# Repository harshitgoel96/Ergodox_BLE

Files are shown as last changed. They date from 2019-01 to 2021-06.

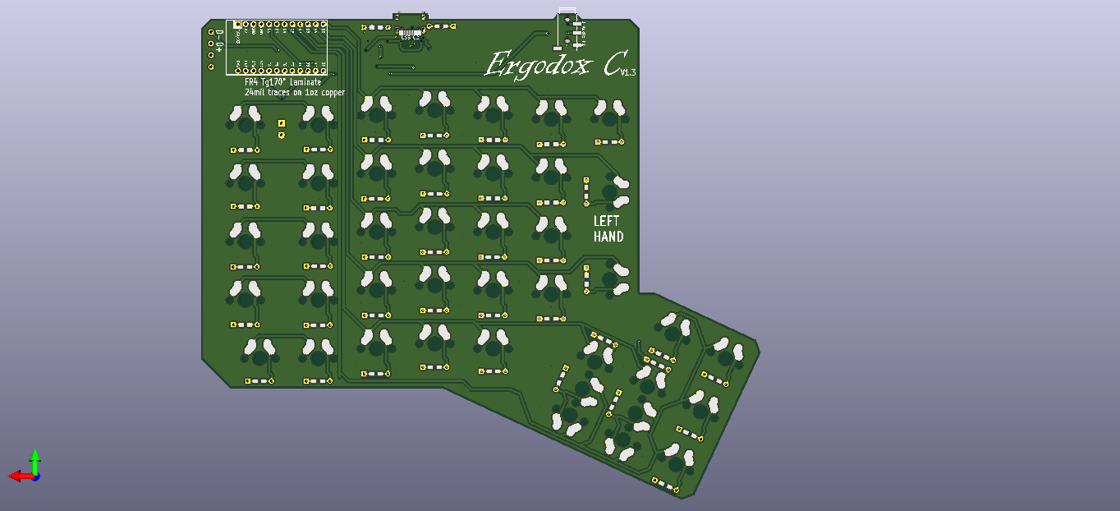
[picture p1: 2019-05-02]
ErgodoxBle/images/Left.png

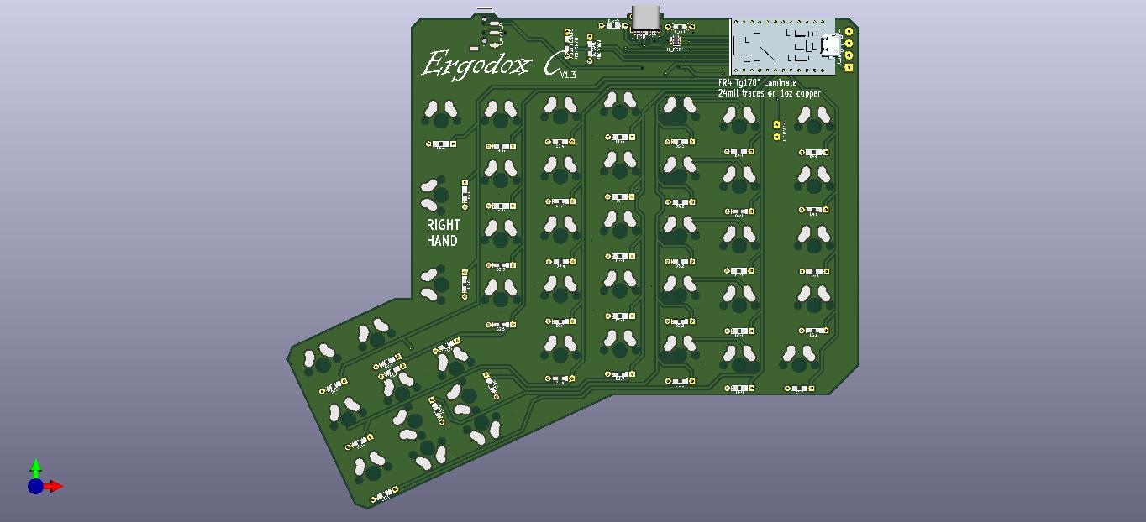
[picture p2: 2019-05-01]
ErgodoxBle/images/Right.jpg

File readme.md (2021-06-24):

# There is no active development on this keyboard. Feel free to do whatever you want. I have moved to Pteron36.
The PCB is in working statue, but no further support or development will be done on this project.
------------------------------------------------------------------------------------------------------------------------------------------
Ergodox BLE
===========

I love my [Ergodox](https://i.imgur.com/aIGm8G6h.jpg) , but it is not Bluetooth. I recently got to know about Bluemicro from u/jpconstantineau which is replacement for pro micro with BLE built in, and I also got to know about Proton C, which has USB C connector and is built for QMK. The original Ergodox uses Tinsy and Ergodone uses pro micro. Both the PCBs don't have support for either of the MCU directly and so I got to work and redid the PCB and I came up with this.

This is my first attempt at making a PCB and I need help from PCB hardware experts if everything is ok or do I need make some changes.

The Ergodox Keyboard was originally developed by “Dox” (Dominic Beauchamp). 

------------------------------------------------------------------------------------------------------------------------------------------
There has ben lot of progress, the complete timeline of the project is available in [Project update](./project_udpate.md) file

First prototype assembled   
Ergodox C

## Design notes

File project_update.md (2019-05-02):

## What has been happening in the project ?

* **8-Jan-2019**  
    Realised ergodox was the best keyboard I have. Need to make one more for home.  

* **9-Jan-2019**  
    Got to know about bluemicro, a ble capable for promicro. Decided that I will make the new ergodox bluetooth.  

* **10-Jan-2019**  
    After chatting with jpconstantineau, realise that existing ergodone or ergodox are not going to work with BlueMicro due to placement issues. Decided to mod only the ergodone case to fit bluemicro on one side.  

* **14-Jan 2019**  
    Further dicusions with jpconstantineau made me realised that i2c at the moment is not supported by bluemicro, and will take time. At the same time got to know about Proton-C. Decided to modify the existing Ergodox PCB.  

* **16-Jan-2019**  
    Modifing existing pcb was tough due to my limited knowledge about kicad.  

* **19-Jan 2019**  
    Role up the sleeve and decided to remake a new pcb.  

* **20-Jan-2019**  
    Added clearance for Proton-C, make sure the edge cuts are within existing Ergodone case.  

* **21-Jan-2019**  
    Realised it was simple enough to change the footprints on the schema and make it work with the kicad libs and footprints that I had.  

* **22-Jan-2019**  
    USB-C is the future, added it to the PCB. Always look to the future.  

* **23-Jan-2019**  
    Generate Gerbers, and schema pdf  to get feedback from a few of people.  

* **24-Jan-2019**  
    Feedback was positive. Gave order to JLCPCB. Fingers crossed.
    
* **30-Jan-2019**   
    Used lister's case to create acrylic case with clearance for USB-C and connection pads.
    
----------------------------------------------------------------------------------------------------------------------------------------

* **24-Mar-2019**
    I have been lazy updating the post, so here are all the updates
    * PCBs have been recieved, wiring looks ok, USB C pads are too small to handsolder, will have to replace it with something more easy to hand solder. ToDo.
    * Bluemicro has been assembled, easy to do if you can ready the marking on PCB and Component reels.
    * I have built the firmware for bluemicro, and did some test unassembeled. Bluetooth working as expected, no latency issues for me so far.
    * PCB has a few diodes in place, just to test things out before I solder in every thing.
    * Female headers are in place to support removal for MCU if and when required. Soldering diodes leg/wire on MCU itself is bit tricky. Trying to make it work at the moment.
* **25-Mar-2019**
    * Finally decided to hard solder the MCU. Firmware mostly works fine, need to flip the right hand mapping to make it work correctly
* **29-Mar-2019**
    * The develop branch of BlueMicro firmware is now being used. There is no connectivity or latency issue being observerd. Currently testing out the keyboard without any layers. This is to test out the hardware and firmware without have any complex code or marcro.
	
----------------------------------------------------------------------------------------------------------------------------------------

* **01-May-2019**
	ErgodoxC v1.3 released. This is most probably the last version of the PCB. Dual side USB C, USB ESD protection have been added. Case design updated for this pcb.
* **02-May-2019**
	Case files updated with plate for Alps Switches.

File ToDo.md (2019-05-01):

ToDo List
=========

This list is just for reference, there is no priority/ETA set for any of these fixes

* ~~USB C footprint used here is not good enough for hand solder, will need to replace with a more expensive one.~~ Decided to keep the smd one due to simpler wiring
* There is no way to access the ON/OFF or replace battery on the case. No idea how I can fix this. Also will need some pins to wire up some pins from bluemicro for easy flashing and support for on/off switch on both CR2032 and Li/Po version. Needs brainstorming.

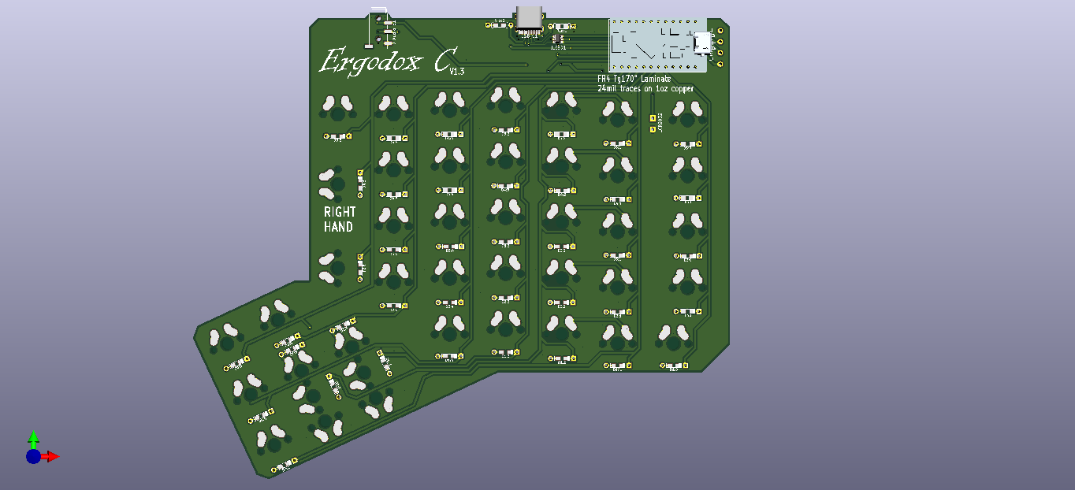
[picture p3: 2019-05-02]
ErgodoxBle/images/Right.png

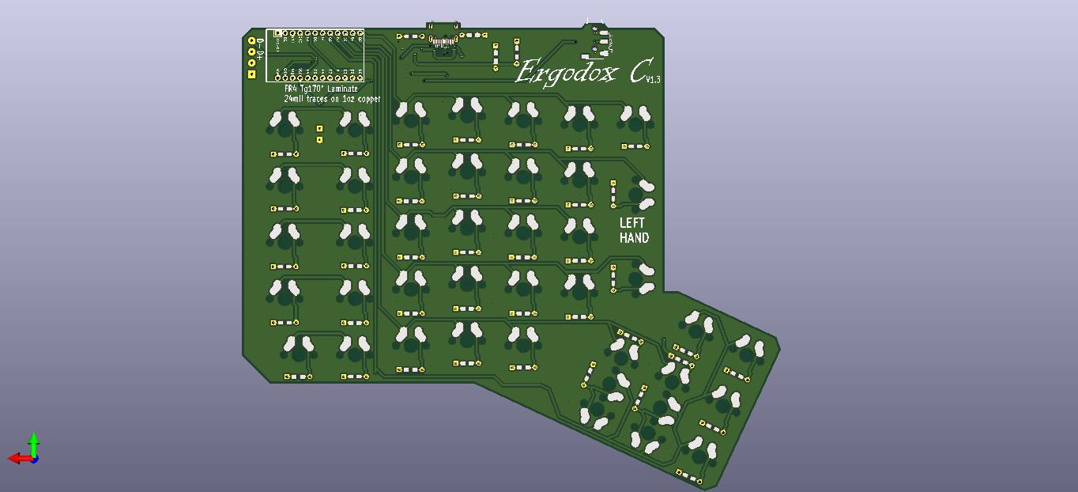
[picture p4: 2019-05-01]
ErgodoxBle/images/Left.jpg

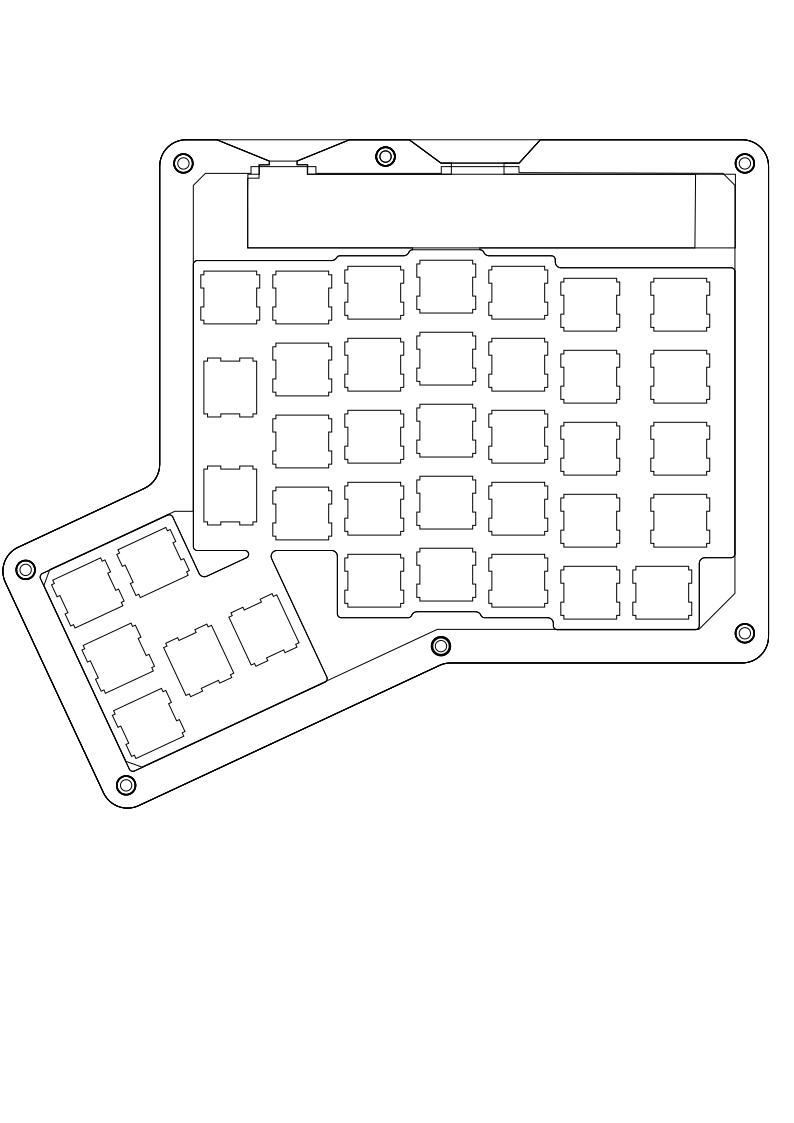
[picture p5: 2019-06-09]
ErgodoxBle Case/all_combined_mx.png

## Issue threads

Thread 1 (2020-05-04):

[question] Key LEDs?

dbernheisel, 2020-05-04:
Does this PCB have support for per-key LEDs?

jottr, 2020-12-08:
@harshitgoel96 Please respond. :)
I'm curious about this too.

harshitgoel96, 2020-12-08:
Hi.

No, it does not support LEDs in current version. I don't have time currently to update the pcb :(

Closed 2020-12-08.

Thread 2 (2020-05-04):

[question] Ordering USB-C board prototype

dbernheisel, 2020-05-04:
First of all, big thank you for publishing these! I absolutely love the Ergodox keyboard and really appreciate you open-sourcing these.

I'm interested in building the USB-C version of this, but I'm also a total newbie on schematics and wiring. I can solder thru-hole components like the key switches and proton-c, but not much else.

I see you've used JLCPCB to order prototypes. Is the [Ergodox-1.3.zip](./ErgodoxBle/ErgodoxC1.3.zip) file the only file to upload to them as-is? And these are the parameters:

|*Parameter*|*Value*|
|---|---|
|Dimensions|200x200mm|
|PCB Thickness|1.6|
|Surface Area|HASL|
|Copper weight|1oz|
|Gold fingers|no|
|paneling|no|
|castellated holes|no|
|different design|1|

It looks like JLCPCB will also do SMT assembly. Do you have any recommendations on how to use that?

I'm uncertain if the included gerber files are for one board, and that board can be used for either the left hand or the right hand, and the only differences is which side I solder the components onto; or if there are two boards in there (different design above?).

harshitgoel96, 2021-04-11:
Hi,
First of all, appologies, this issue missed my sights.
the pcb is not designed to be used with smt service. it was manly designed with hand soldering in mind. jlcpcb will require only the zip to be uploaded, and it will auto calculate everything.
i did not use the jlcpcb smt service so wont be able to comment on that.
there is only one board, and you flip it for second half.

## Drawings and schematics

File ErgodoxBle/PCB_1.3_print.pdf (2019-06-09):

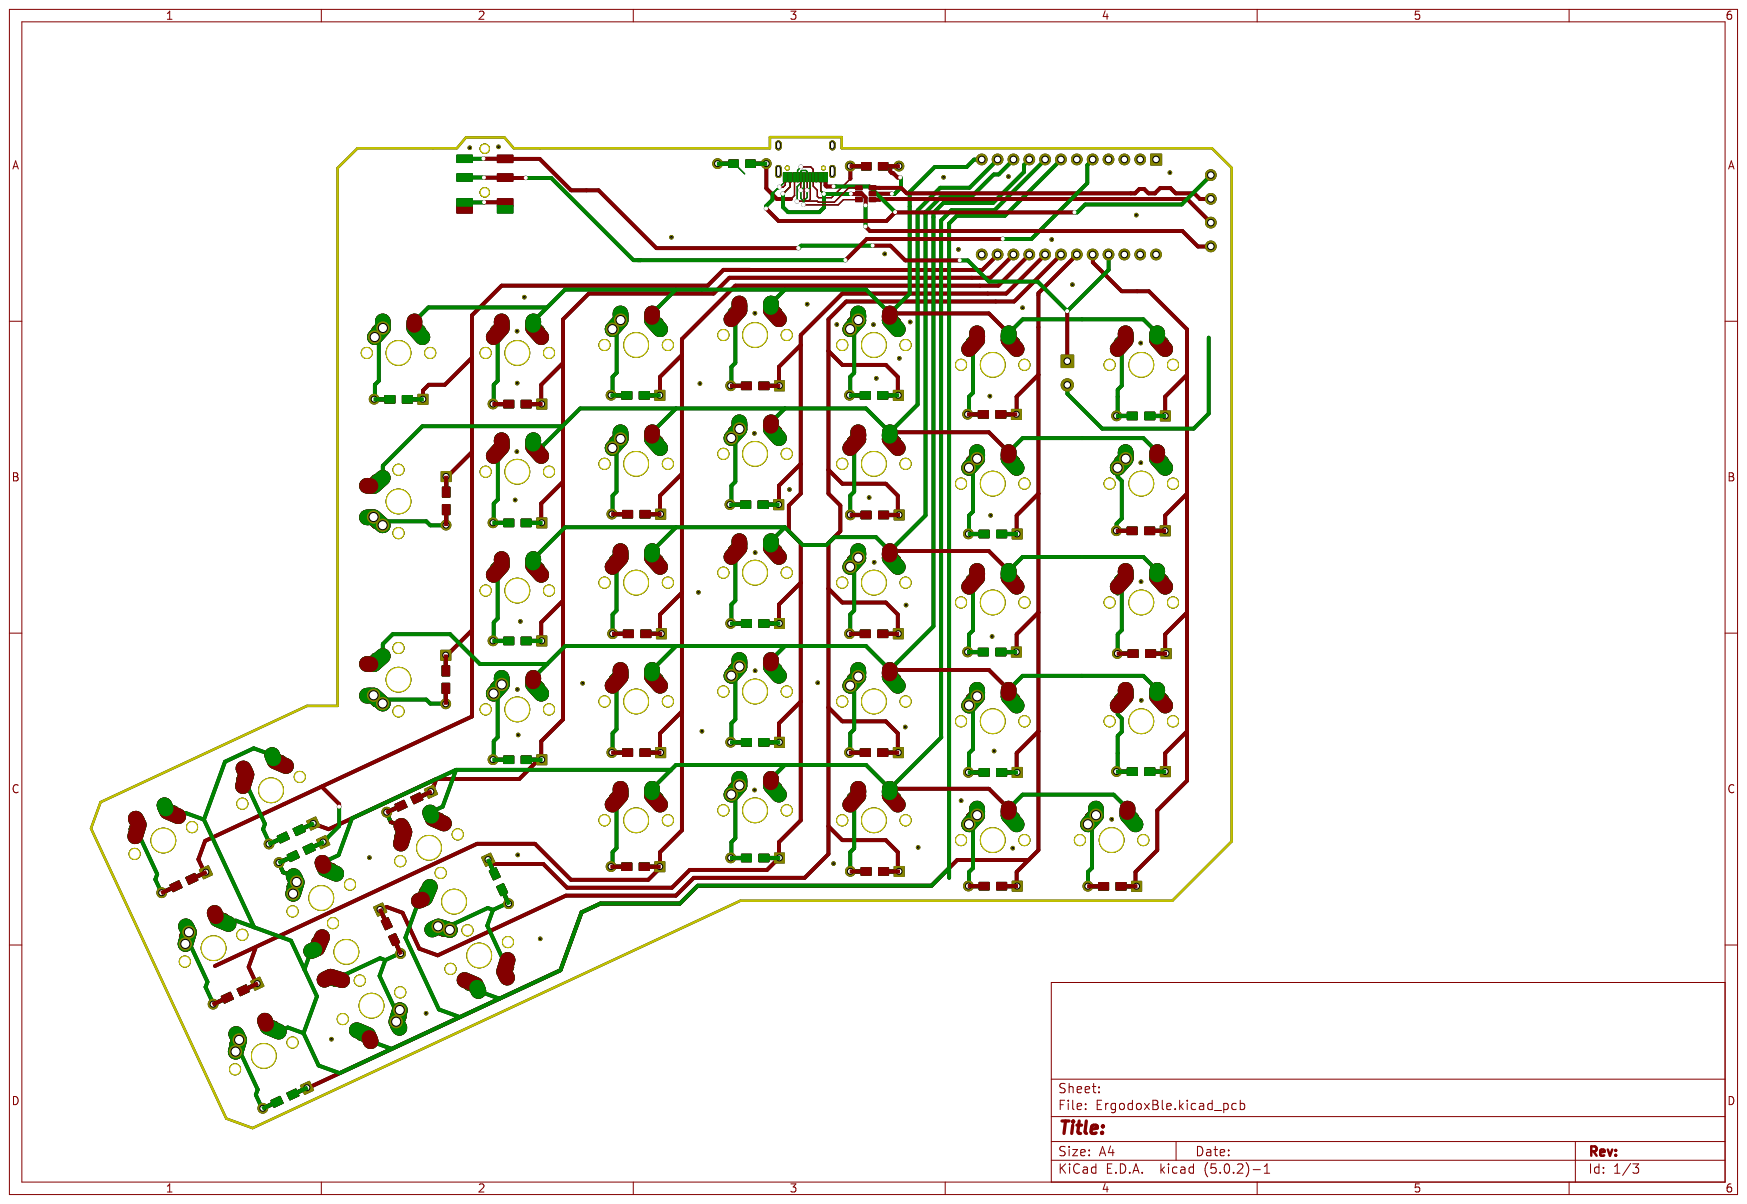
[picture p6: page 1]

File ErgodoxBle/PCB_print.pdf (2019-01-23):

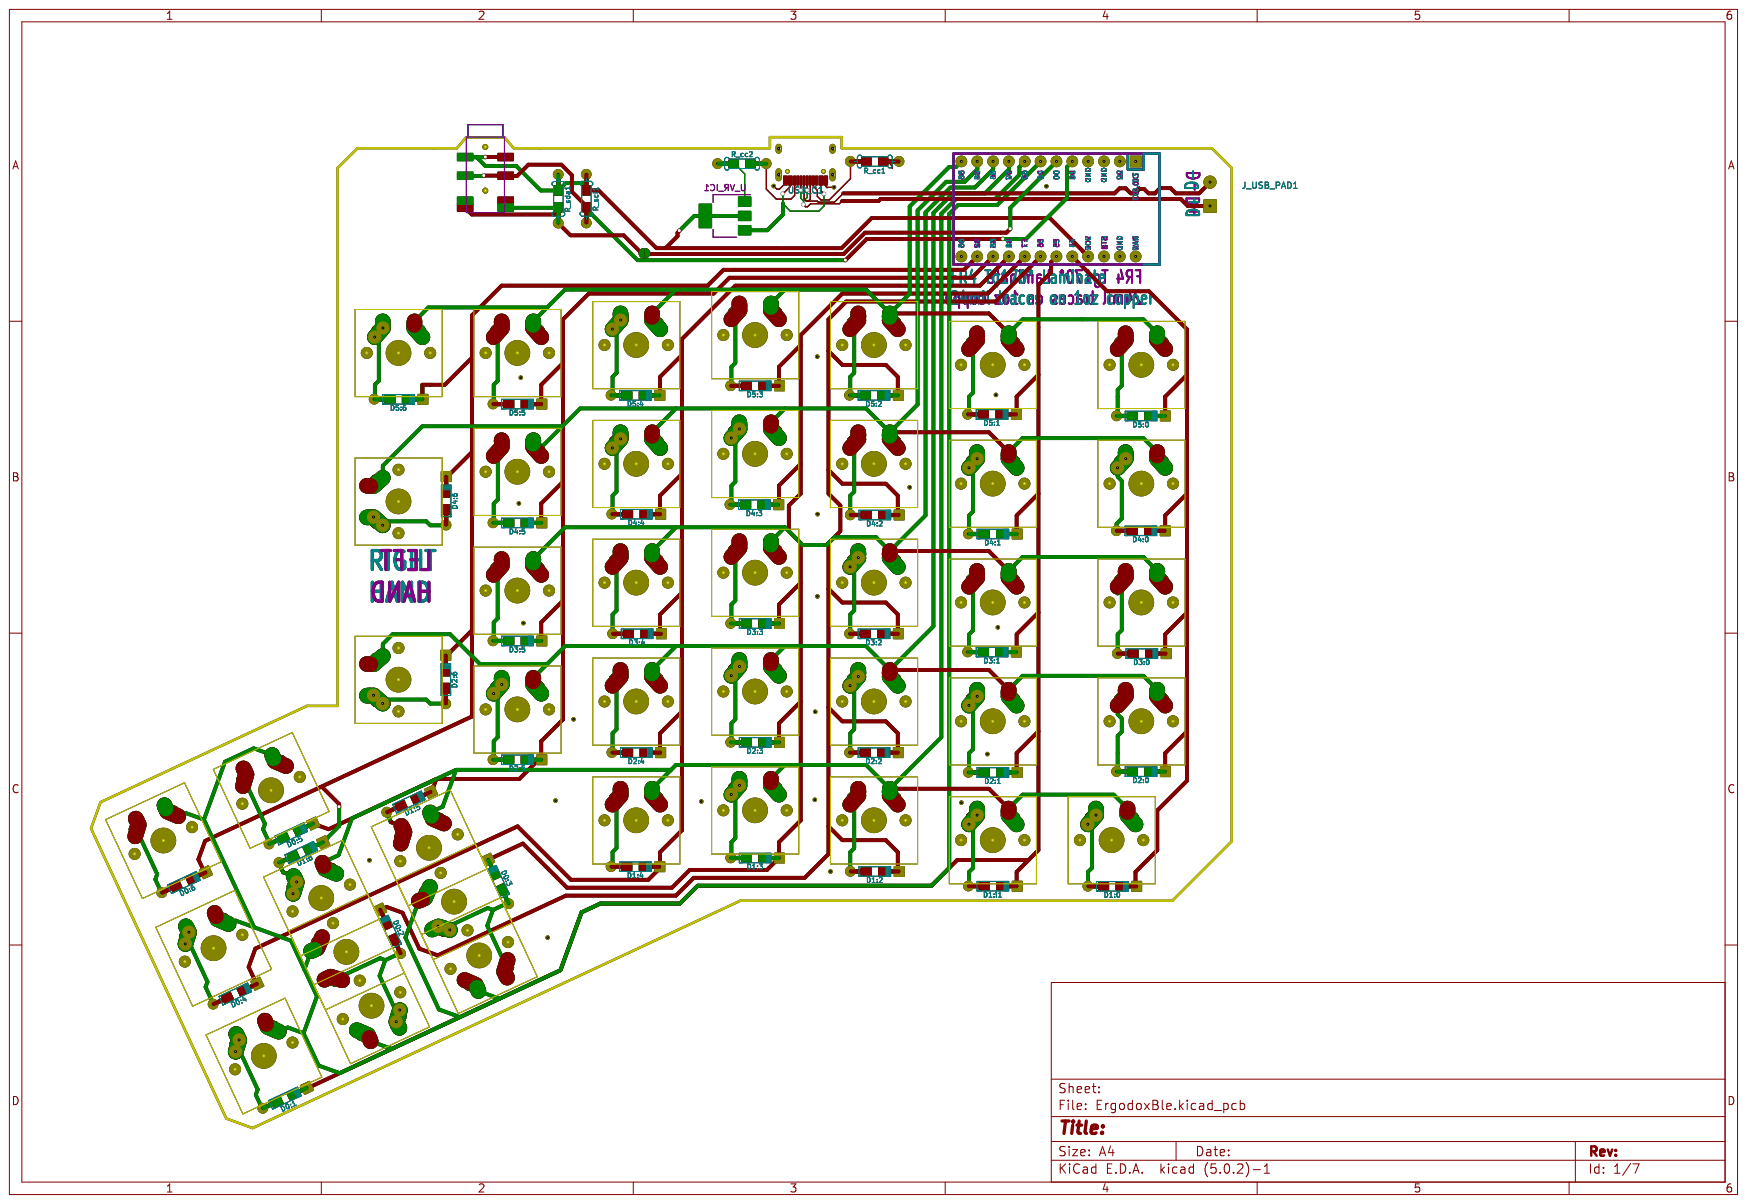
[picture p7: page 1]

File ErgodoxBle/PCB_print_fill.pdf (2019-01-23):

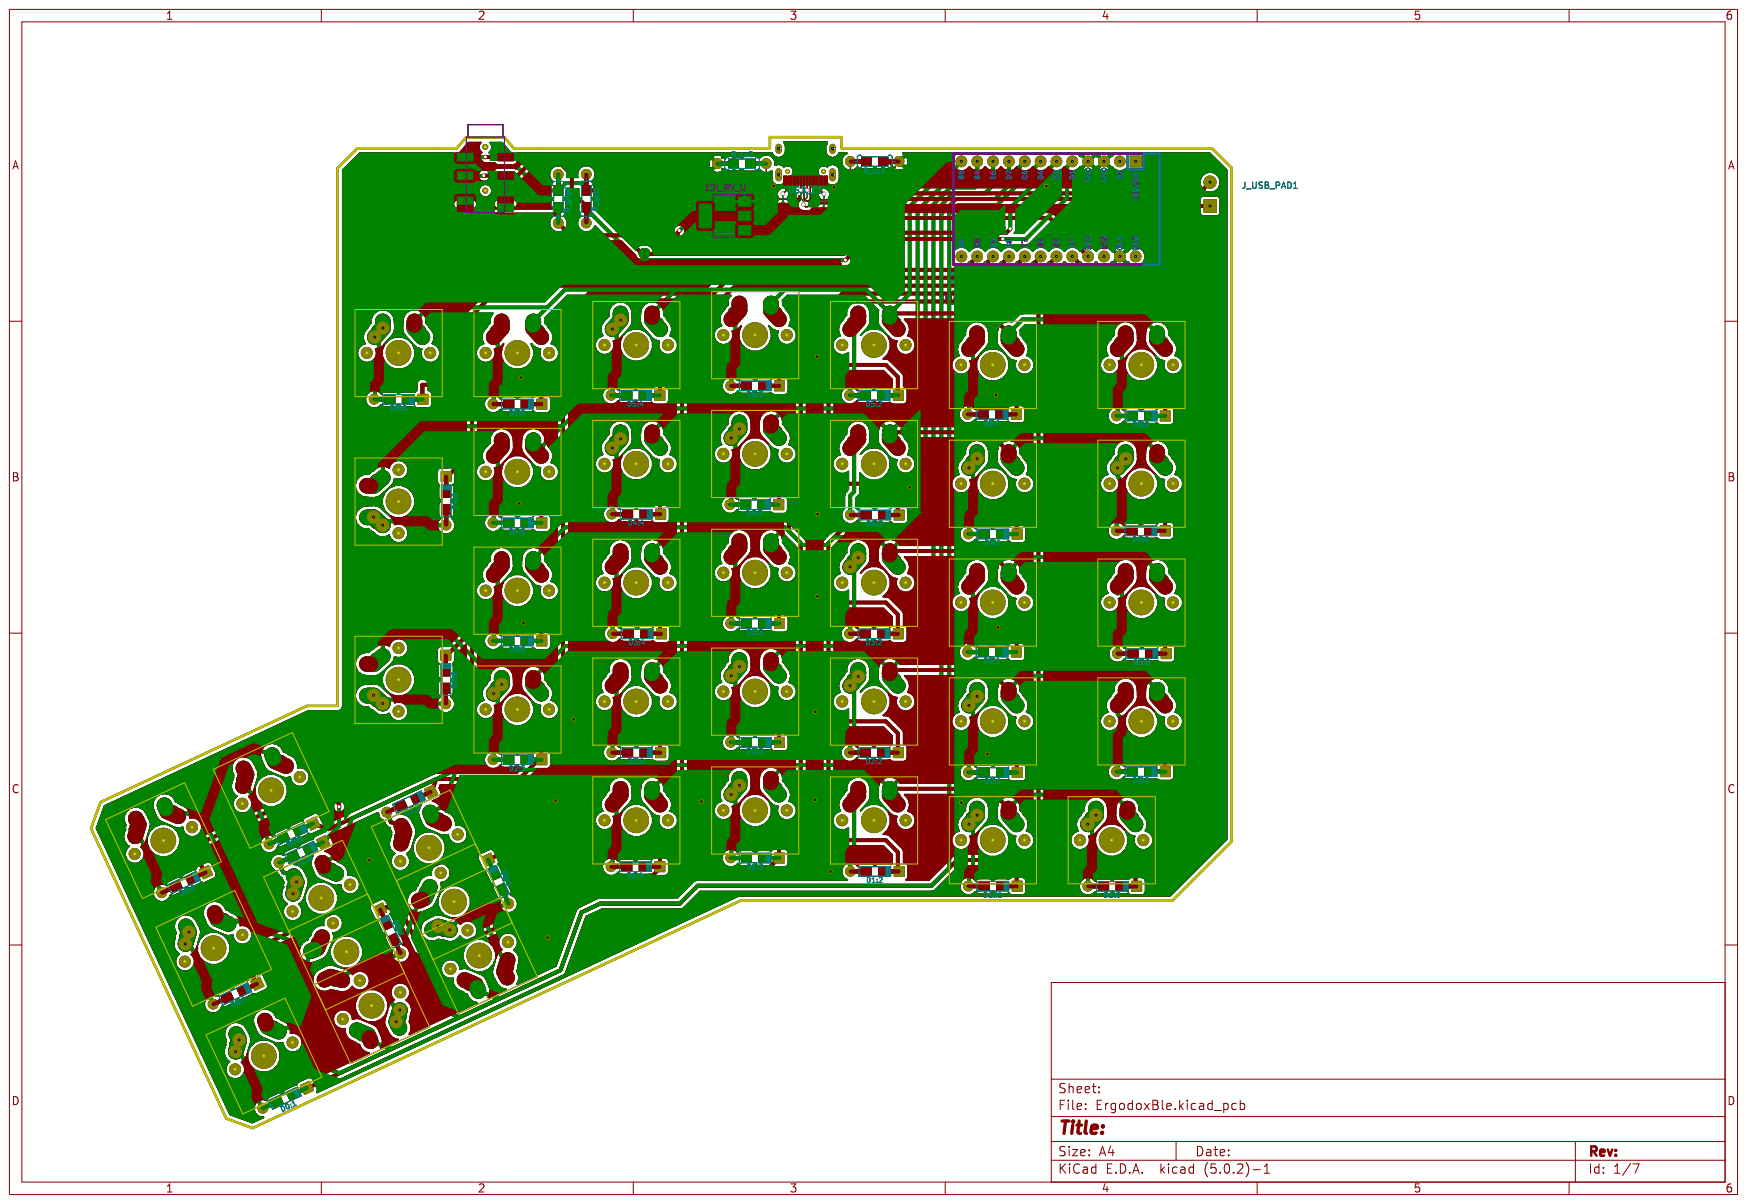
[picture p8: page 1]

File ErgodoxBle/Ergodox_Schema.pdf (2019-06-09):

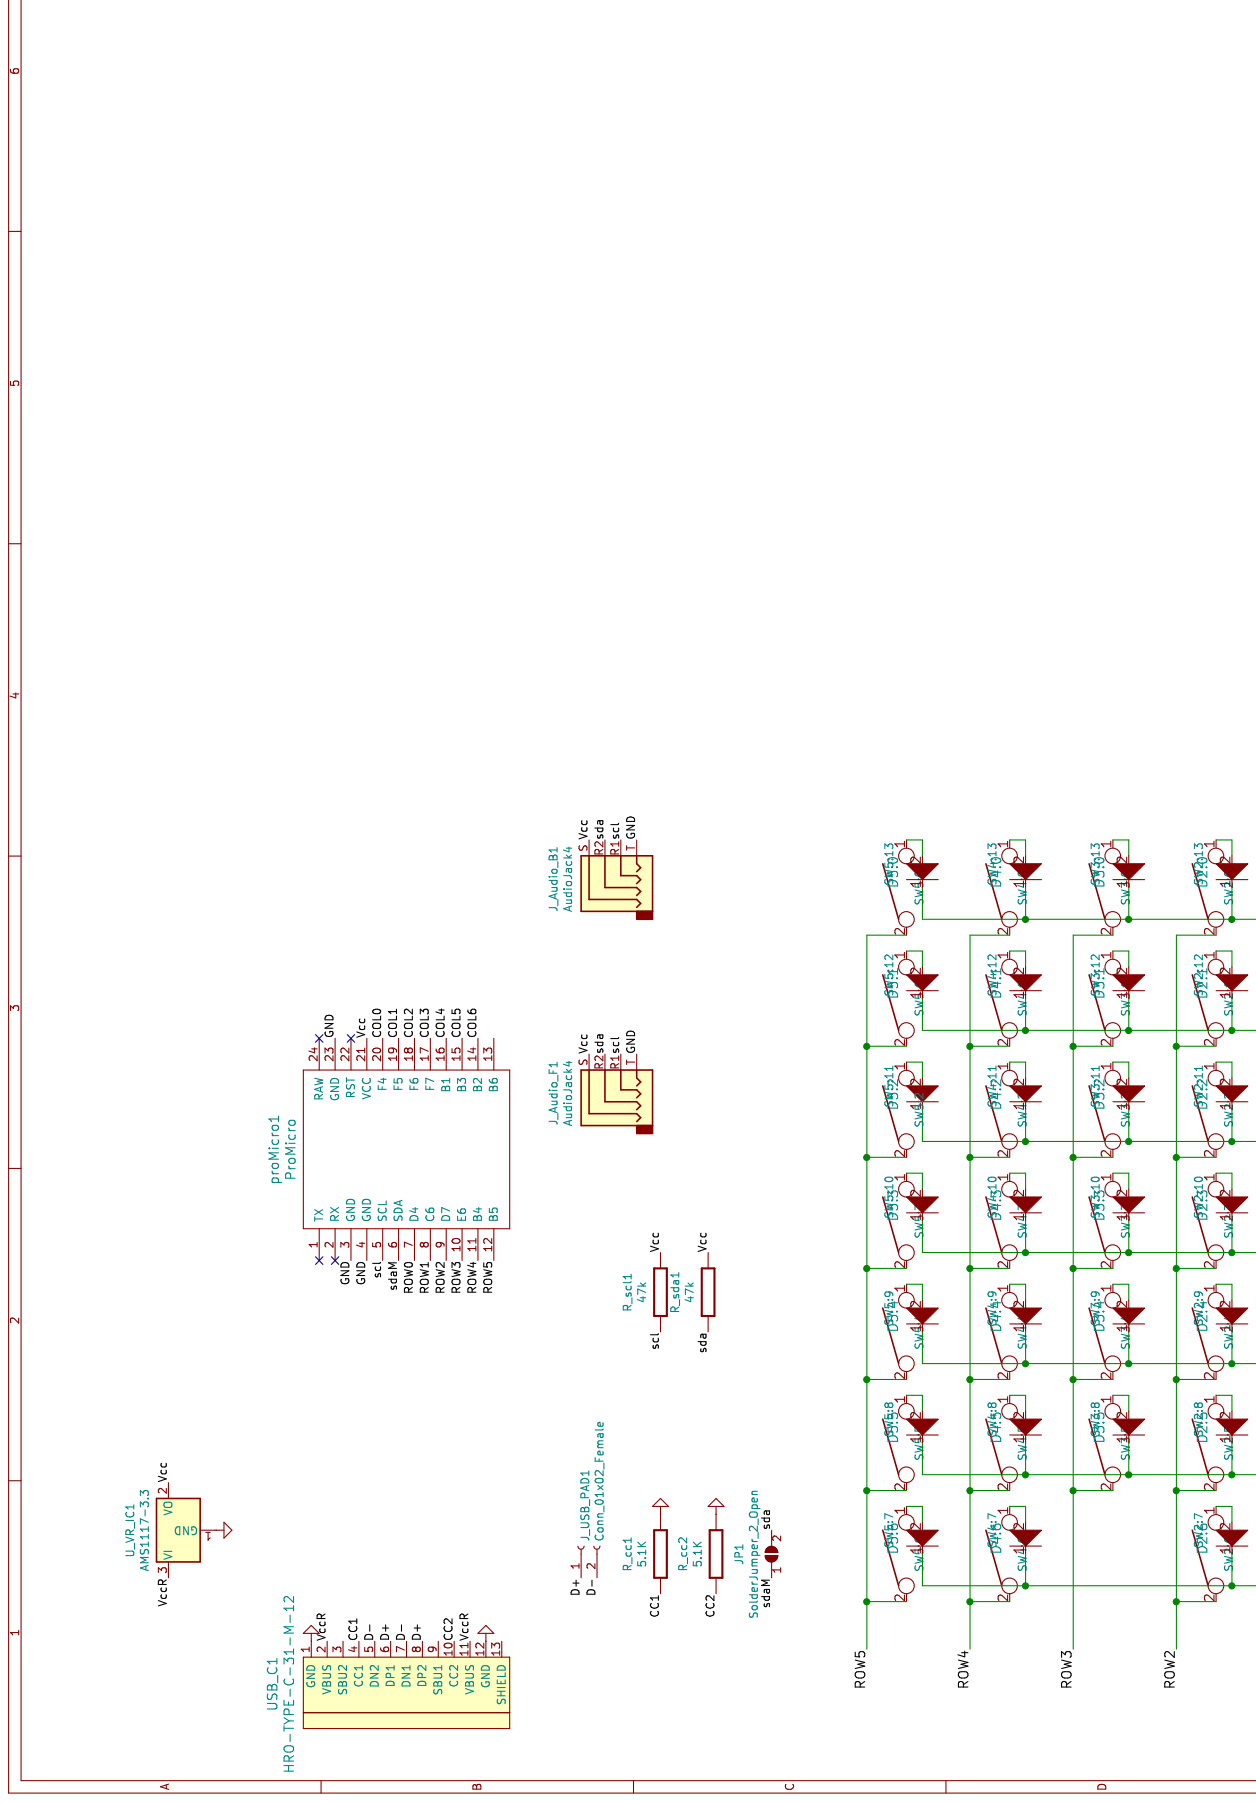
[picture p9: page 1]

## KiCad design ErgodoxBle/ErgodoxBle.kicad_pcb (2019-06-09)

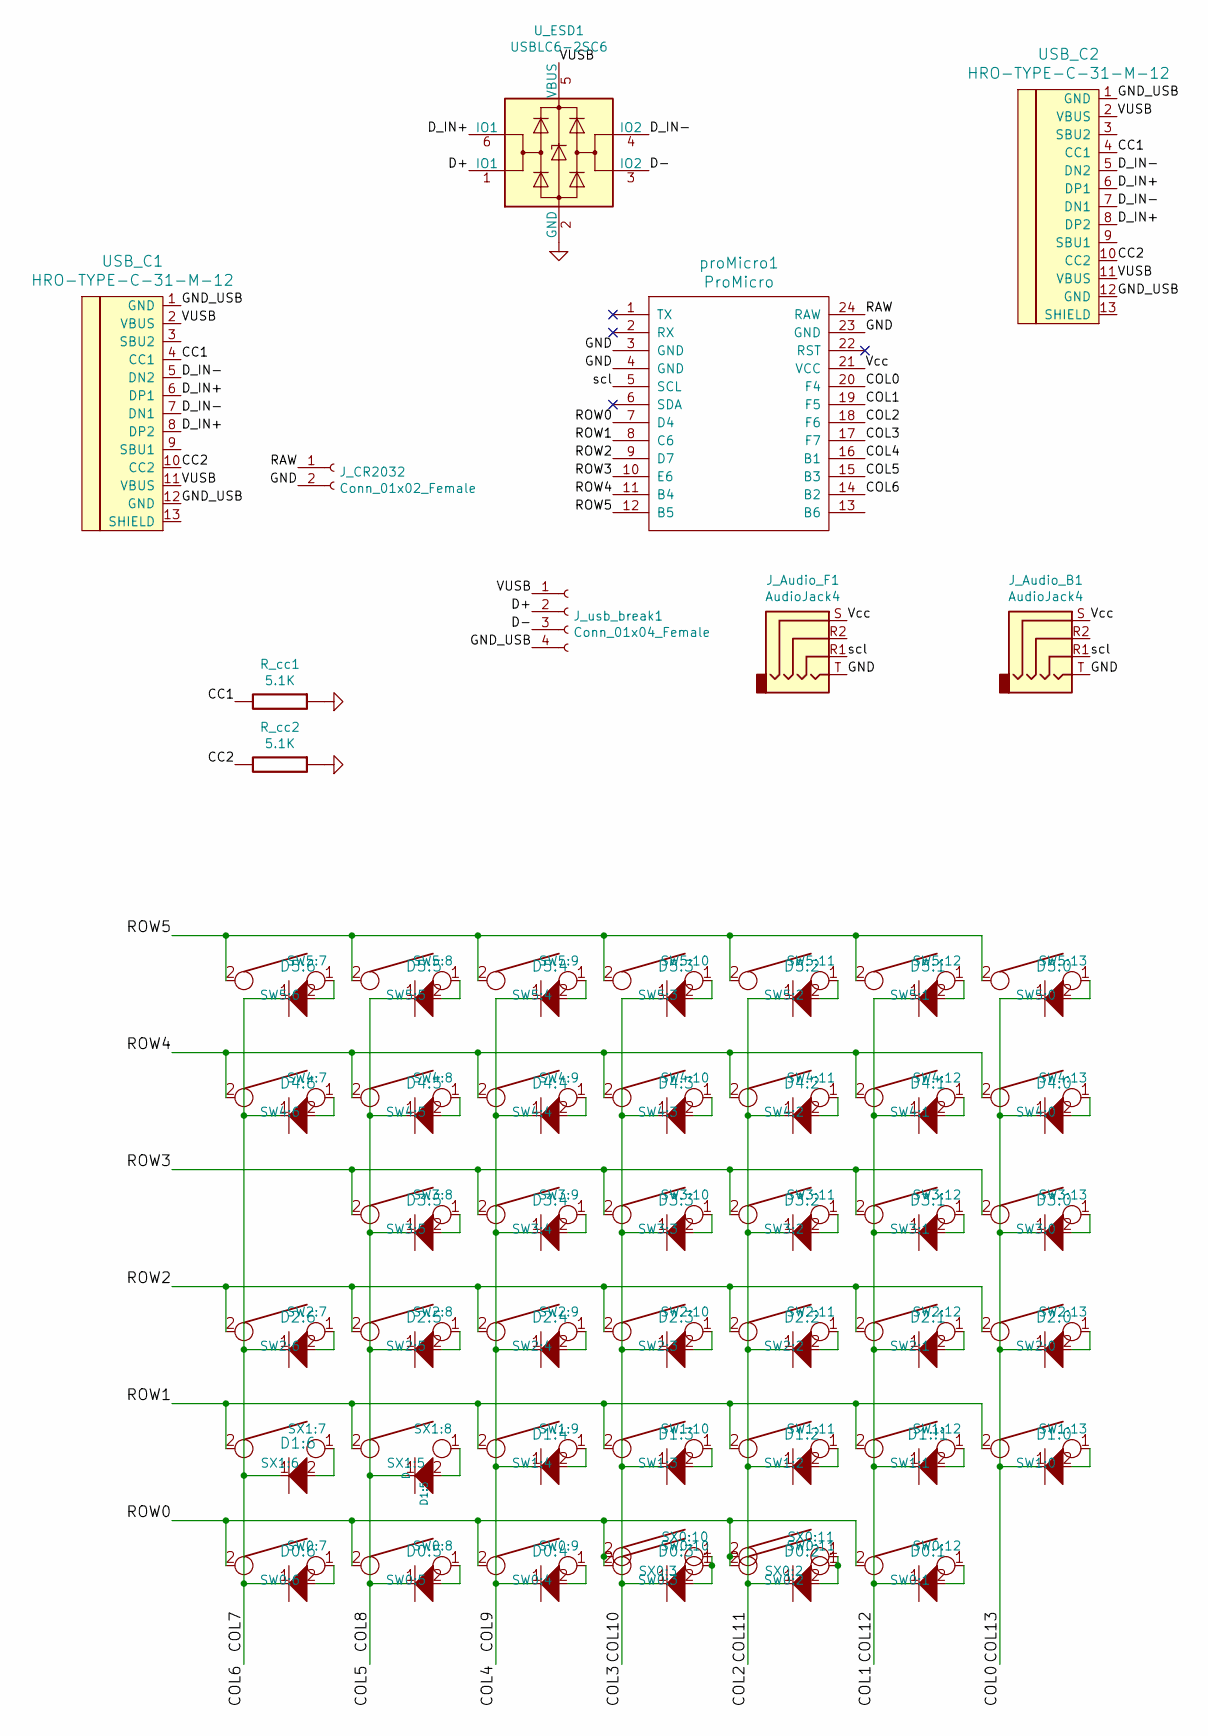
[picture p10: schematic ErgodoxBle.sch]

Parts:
D0:1, D0:2, D0:3, D0:4, D0:5, D0:6, D1:0, D1:2, D1:3, D1:4, D1:5, D1:6, D1:!1, D2:0, D2:1, D2:2, D2:3, D2:4, D2:5, D2:6, D3:0, D3:1, D3:2, D3:3, D3:4, D3:5, D4:0, D4:1, D4:2, D4:3, D4:4, D4:5, D4:6, D5:0, D5:1, D5:2, D5:3, D5:4, D5:5, D5:6: D; Diode-dual
J_Audio_B1: AudioJack4; Jack_3.5mm_PJ320D_Horizontal
J_Audio_F1: AudioJack4; Jack_3.5mm_PJ320D_Horizontal
J_CR2032: Conn_01x02_Female; Custom_SolderWirePad_1x02_P1.75mm_Drill1.09mm
J_usb_break1: Conn_01x04_Female; Custom_SolderWirePad_1x04_P1.7526mm_Drill1.0922mm
R_cc1, R_cc2: 5.1K; Resistor-Hybrid
SW0:7: SW0:6; Hybrid_PCB_100H_Dual_hole
SW0:8: SW0:5; Hybrid_PCB_100H_Dual_hole
SW0:9: SW0:4; Hybrid_PCB_100H_Dual_hole
SW0:10: SW0:3; Hybrid_PCB_200H-dual
SW0:11: SW0:2; Hybrid_PCB_200H-dual
SW0:12: SW0:1; Hybrid_PCB_100H_Dual_hole
SW1:9: SW1:4; Hybrid_PCB_100H_Dual_hole
SW1:10: SW1:3; Hybrid_PCB_100H_Dual_hole
SW1:11: SW1:2; Hybrid_PCB_100H_Dual_hole
SW1:12: SW1:1; Hybrid_PCB_100H_Dual_hole
SW1:13: SW1:0; Hybrid_PCB_100H_Dual_hole
SW2:7: SW2:6; Hybrid_PCB_100H_Dual_hole
SW2:8: SW2:5; Hybrid_PCB_100H_Dual_hole
SW2:9: SW2:4; Hybrid_PCB_100H_Dual_hole
SW2:10: SW2:3; Hybrid_PCB_100H_Dual_hole
SW2:11: SW2:2; Hybrid_PCB_100H_Dual_hole
SW2:12: SW2:1; Hybrid_PCB_100H_Dual_hole
SW2:13: SW2:0; correct_Hybrid_PCB_100v_150H_Dual_hole
SW3:8: SW3:5; Hybrid_PCB_100H_Dual_hole
SW3:9: SW3:4; Hybrid_PCB_100H_Dual_hole
SW3:10: SW3:3; Hybrid_PCB_100H_Dual_hole
SW3:11: SW3:2; Hybrid_PCB_100H_Dual_hole
SW3:12: SW3:1; Hybrid_PCB_100H_Dual_hole
SW3:13: SW3:0; correct_Hybrid_PCB_100v_150H_Dual_hole
SW4:7: SW4:6; Hybrid_PCB_100H_Dual_hole
SW4:8: SW4:5; Hybrid_PCB_100H_Dual_hole
SW4:9: SW4:4; Hybrid_PCB_100H_Dual_hole
SW4:10: SW4:3; Hybrid_PCB_100H_Dual_hole
SW4:11: SW4:2; Hybrid_PCB_100H_Dual_hole
SW4:12: SW4:1; Hybrid_PCB_100H_Dual_hole
SW4:13: SW4:0; correct_Hybrid_PCB_100v_150H_Dual_hole
SW5:7: SW5:6; Hybrid_PCB_100H_Dual_hole
SW5:8: SW5:5; Hybrid_PCB_100H_Dual_hole
SW5:9: SW5:4; Hybrid_PCB_100H_Dual_hole
SW5:10: SW5:3; Hybrid_PCB_100H_Dual_hole
SW5:11: SW5:2; Hybrid_PCB_100H_Dual_hole
SW5:12: SW5:1; Hybrid_PCB_100H_Dual_hole
SW5:13: SW5:0; correct_Hybrid_PCB_100v_150H_Dual_hole
SX0:10: SX0:3; Hybrid_PCB_100H_Dual_hole
SX0:11: SX0:2; Hybrid_PCB_100H_Dual_hole
SX1:7: SX1:6; Hybrid_PCB_100H_Dual_hole
SX1:8: SX1:5; Hybrid_PCB_100H_Dual_hole
USB_C1, USB_C2: HRO-TYPE-C-31-M-12
U_ESD1: USBLC6-2SC6; SOT-23-6
proMicro1: ProMicro; ArduinoProMicro

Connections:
/CC1: R_cc1.2, USB_C1.4 (CC1), USB_C2.4 (CC1)
/CC2: R_cc2.2, USB_C1.10 (CC2), USB_C2.10 (CC2)
/COL0: D1:0.1, D2:0.1, D3:0.1, D4:0.1, D5:0.1, proMicro1.20 (F4)
/COL1: D0:1.1, D1:!1.1, D2:1.1, D3:1.1, D4:1.1, D5:1.1, proMicro1.19 (F5)
/COL4: D0:4.1, D1:4.1, D2:4.1, D3:4.1, D4:4.1, D5:4.1, proMicro1.16 (B1)
/COL5: D0:5.1, D1:5.1, D2:5.1, D3:5.1, D4:5.1, D5:5.1, proMicro1.15 (B3)
/COL6: D0:6.1, D1:6.1, D2:6.1, D4:6.1, D5:6.1, proMicro1.14 (B2)
/COL10: D0:3.1, D1:3.1, D2:3.1, D3:3.1, D4:3.1, D5:3.1, proMicro1.17 (F7)
/COL11: D0:2.1, D1:2.1, D2:2.1, D3:2.1, D4:2.1, D5:2.1, proMicro1.18 (F6)
/D+: J_usb_break1.2, U_ESD1.1 (IO1)
/D-: J_usb_break1.3, U_ESD1.3 (IO2)
/D_IN+: USB_C1.6 (DP1), USB_C1.8 (DP2), USB_C2.6 (DP1), USB_C2.8 (DP2), U_ESD1.6 (IO1)
/D_IN-: USB_C1.5 (DN2), USB_C1.7 (DN1), USB_C2.5 (DN2), USB_C2.7 (DN1), U_ESD1.4 (IO2)
/GND_USB: J_usb_break1.4, USB_C1.1 (GND), USB_C1.12 (GND), USB_C2.1 (GND), USB_C2.12 (GND)
/RAW: J_CR2032.1, proMicro1.24 (RAW)
/ROW0: SW0:7.2, SW0:8.2, SW0:9.2, SW0:10.2, SW0:11.2, SW0:12.2, SX0:10.2, SX0:11.2, proMicro1.7 (D4)
/ROW1: SW1:9.2, SW1:10.2, SW1:11.2, SW1:12.2, SW1:13.2, SX1:7.2, SX1:8.2, proMicro1.8 (C6)
/ROW2: SW2:7.2, SW2:8.2, SW2:9.2, SW2:10.2, SW2:11.2, SW2:12.2, SW2:13.2, proMicro1.9 (D7)
/ROW3: SW3:8.2, SW3:9.2, SW3:10.2, SW3:11.2, SW3:12.2, SW3:13.2, proMicro1.10 (E6)
/ROW4: SW4:7.2, SW4:8.2, SW4:9.2, SW4:10.2, SW4:11.2, SW4:12.2, SW4:13.2, proMicro1.11 (B4)
/ROW5: SW5:7.2, SW5:8.2, SW5:9.2, SW5:10.2, SW5:11.2, SW5:12.2, SW5:13.2, proMicro1.12 (B5)
/VUSB: J_usb_break1.1, USB_C1.2 (VBUS), USB_C1.11 (VBUS), USB_C2.2 (VBUS), USB_C2.11 (VBUS), U_ESD1.5 (VBUS)
/Vcc: J_Audio_B1.S, J_Audio_F1.S, proMicro1.21 (VCC)
/scl: J_Audio_B1.R1, J_Audio_F1.R1, proMicro1.5 (SCL)
GND: J_Audio_B1.T, J_Audio_F1.T, J_CR2032.2, R_cc1.1, R_cc2.1, U_ESD1.2 (GND), proMicro1.3 (GND), proMicro1.4 (GND), proMicro1.23 (GND)
unnamed: D0:1.2, SW0:12.1
unnamed: D0:2.2, SW0:11.1, SX0:11.1
unnamed: D0:3.2, SW0:10.1, SX0:10.1
unnamed: D0:4.2, SW0:9.1
unnamed: D0:5.2, SW0:8.1
unnamed: D0:6.2, SW0:7.1
unnamed: D1:0.2, SW1:13.1
unnamed: D1:2.2, SW1:11.1
unnamed: D1:3.2, SW1:10.1
unnamed: D1:4.2, SW1:9.1
unnamed: D1:5.2, SX1:8.1
unnamed: D1:6.2, SX1:7.1
unnamed: D1:!1.2, SW1:12.1
unnamed: D2:0.2, SW2:13.1
unnamed: D2:1.2, SW2:12.1
unnamed: D2:2.2, SW2:11.1
unnamed: D2:3.2, SW2:10.1
unnamed: D2:4.2, SW2:9.1
unnamed: D2:5.2, SW2:8.1
unnamed: D2:6.2, SW2:7.1
unnamed: D3:0.2, SW3:13.1
unnamed: D3:1.2, SW3:12.1
unnamed: D3:2.2, SW3:11.1
unnamed: D3:3.2, SW3:10.1
unnamed: D3:4.2, SW3:9.1
unnamed: D3:5.2, SW3:8.1
unnamed: D4:0.2, SW4:13.1
unnamed: D4:1.2, SW4:12.1
unnamed: D4:2.2, SW4:11.1
unnamed: D4:3.2, SW4:10.1
unnamed: D4:4.2, SW4:9.1
unnamed: D4:5.2, SW4:8.1
unnamed: D4:6.2, SW4:7.1
unnamed: D5:0.2, SW5:13.1
unnamed: D5:1.2, SW5:12.1
unnamed: D5:2.2, SW5:11.1
unnamed: D5:3.2, SW5:10.1
unnamed: D5:4.2, SW5:9.1
unnamed: D5:5.2, SW5:8.1
unnamed: D5:6.2, SW5:7.1

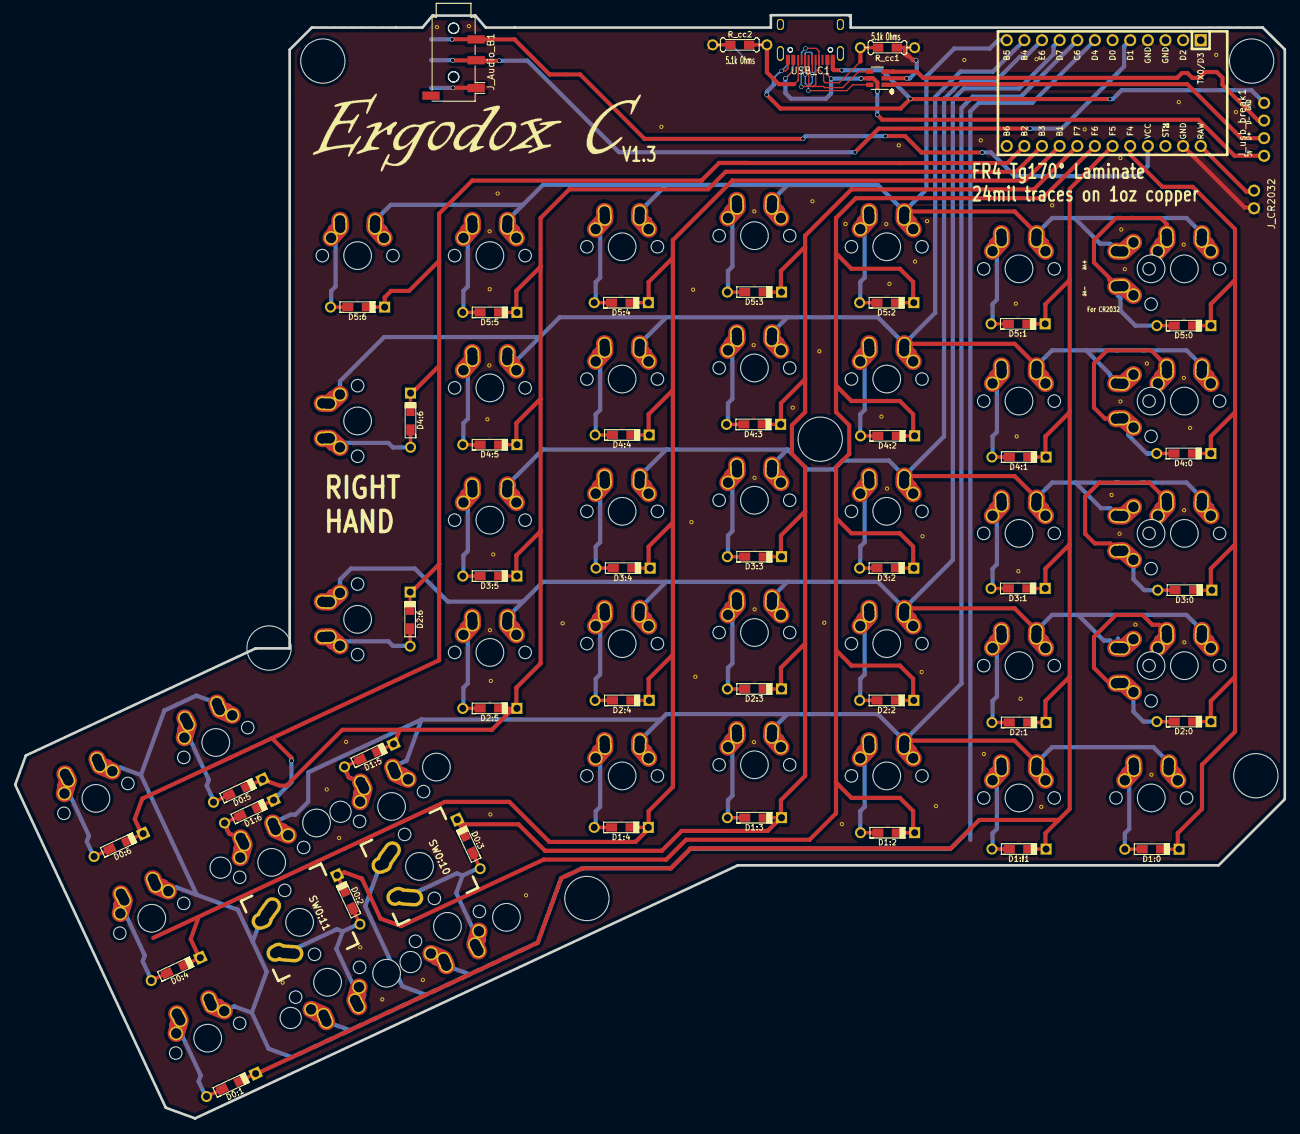
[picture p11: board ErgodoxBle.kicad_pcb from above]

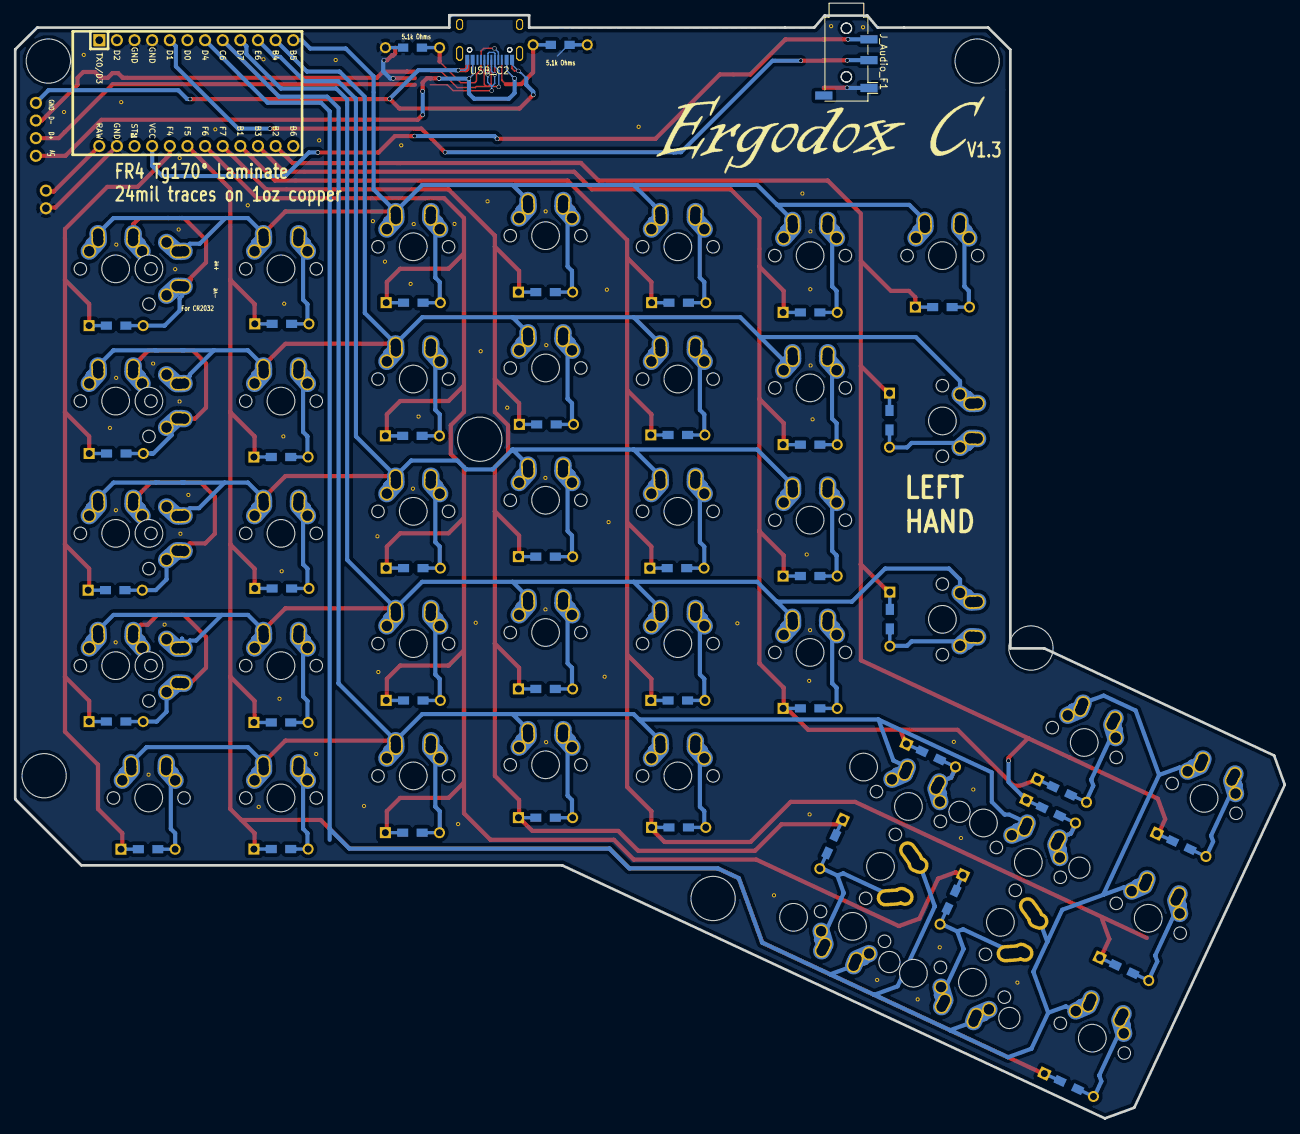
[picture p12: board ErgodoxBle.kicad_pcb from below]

Board: 2 copper layers, 182.8 x 158.9 mm, 92 parts (2 on the bottom side), 65 nets.

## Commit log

2019-01-20 finish prototype
    [ErgodoxBle.kicad_pcb, ErgodoxBle.sch]
2019-01-20 use correct switch footprint
    [ErgodoxBle.kicad_pcb, ErgodoxBle.sch]
2019-01-20 generate gerber files for inspection
    [ErgodoxBle-B.Cu.gbl, ErgodoxBle-B.Mask.gbs, ErgodoxBle-B.Paste.gbp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]
2019-01-20 align the pcb with ergodone case
    [ErgodoxBle.kicad_pcb]
2019-01-20 updated gerber files
    [ErgodoxBle-B.Cu.gbl, ErgodoxBle-B.Mask.gbs, ErgodoxBle-B.Paste.gbp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]
2019-01-20 add solder jumpber on both layers
    [ErgodoxBle.kicad_pcb, ErgodoxBle.sch]
2019-01-20 added clearence for ProtonC
    [ErgodoxBle.kicad_pcb, ErgodoxBle.sch]
2019-01-20 remove obsolete gerber files
    [ErgodoxBle-B.Cu.gbl, ErgodoxBle-B.Mask.gbs, ErgodoxBle-B.Paste.gbp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]
2019-01-20 gerber updated
    [ErgodoxBle-B.Cu.gbl, ErgodoxBle-B.Mask.gbs, ErgodoxBle-B.Paste.gbp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]
2019-01-21 Redo the existing ergodox pcb
    [ErgodoxBle.kicad_pcb, ErgodoxBle.sch]
2019-01-22 Added USB-C
    [ErgodoxBle-B.Cu.gbl, ErgodoxBle-B.Mask.gbs, ErgodoxBle-B.Paste.gbp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]
2019-01-22 finalize pcb
    [ErgodoxBle-B.Mask.gbs, ErgodoxBle-B.Paste.gbp, ErgodoxBle-B.SilkS.gbo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]
2019-01-23 schema and pcb pdf
    [ErgodoxBle.kicad_pcb, ErgodoxBle.sch]
2019-01-23 updated USB-C pad and added zone filled pdf
    [ErgodoxBle.kicad_pcb]
2019-01-26 add project time line
    [ErgodoxBle-B.Mask.gbs, ErgodoxBle-B.Paste.gbp, ErgodoxBle-B.SilkS.gbo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]
2019-01-30 case added
2019-01-30 update entry for case
2019-01-31 add dxf version
    [bottom.dxf, plate.dxf, spacer_bottom.dxf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]
2019-03-28 update pcb, removed unwanted i2c wire, will go only serial over sda
    [ErgodoxBle.kicad_pcb, ErgodoxBle.sch]
2019-03-29 Added pad for CR2032 module for bluemicro
    [ErgodoxBle-B.Mask.gbs, ErgodoxBle-B.SilkS.gbo, ErgodoxBle-Back.gbl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]
2019-04-27 v 1.3, almost the final version
    [ErgodoxBle-B.Mask.gbs, ErgodoxBle-B.Paste.gbp, ErgodoxBle-B.SilkS.gbo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]
2019-04-29 final version before hardware testing
    [ErgodoxBle.kicad_pcb, ErgodoxBle.sch]
2019-05-01 minor changes
    [ErgodoxBle-B.Mask.gbs, ErgodoxBle-B.Paste.gbp, ErgodoxBle-B.SilkS.gbo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]
2019-05-01 update case design to allow M3 round standoff, 5mm OD, 3mm ID
2019-05-02 align front and back usb c port
    [ErgodoxBle-B.Mask.gbs, ErgodoxBle-B.SilkS.gbo, ErgodoxBle-Back.gbl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]
2019-05-02 redo fill zone
    [ErgodoxBle.kicad_pcb]
2019-05-02 add plate for alps switch
2019-05-02 remove obsolete file
    [bottom.dxf, plate.dxf, spacer_bottom.dxf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]
2019-06-09 added svg for case
    [ErgodoxBle.kicad_pcb, ErgodoxBle.sch]
